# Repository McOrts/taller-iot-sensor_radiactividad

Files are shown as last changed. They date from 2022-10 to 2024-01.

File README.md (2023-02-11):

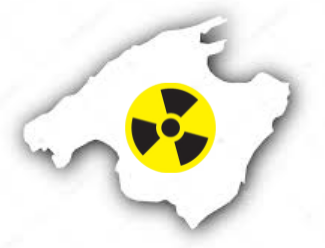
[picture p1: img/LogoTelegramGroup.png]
#  Taller sensor IoT de radiactividad
Taller IoT para construir un medidor Geiger conectado. Basado en el ESP8266, MQTT, Node-RED e integrado en la red GMC

La solución tecnológica utilizada para la plataforma de despliegue de servicios y datos. Está basada en hardware y software libre. 

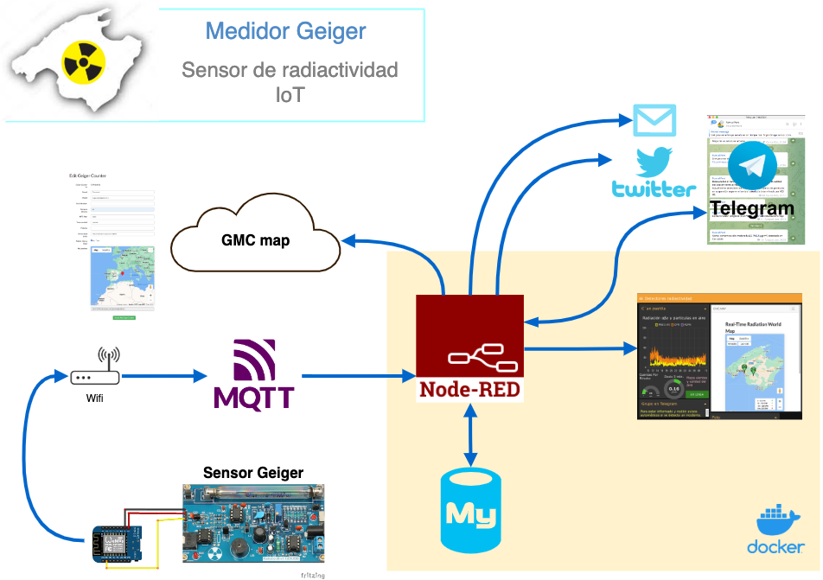
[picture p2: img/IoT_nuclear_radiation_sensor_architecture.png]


## Componentes que vamos a utilizar
**Hardware**
- [ ] 1 x [WEMOS D1 Mini Pro 16 MBytes con antena externa](https://www.aliexpress.com/item/32801063577.html)
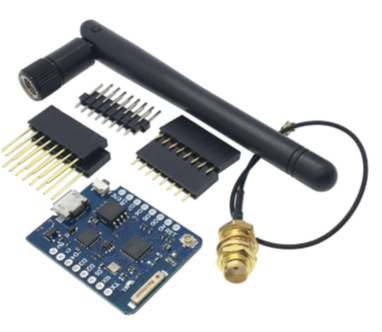
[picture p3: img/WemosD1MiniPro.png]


La placa de prototipo Wemos D1 Mini es microcontrolador muy versátil y de tamaño reducido.
  - Permite ser programado directamente desde el IDE de Arduino.
  - Ofrece pines de voltajes de salida de 3,2V y 5V.
<br>
  - Tiene conectividad Wi-Fi con todo el _stack_ de TCP/IP.
<br>
  - Incluye el chip CP2104 USB-TO-UART IC
<br>
  - El microcontrolador incorporado es el ESP-8266EX
<br>
    _  * Con un voltaje de funcionamiento: 3,3 V (chip) 5 V (placa)
<br>
    _  * Tiene 11 pines de E/S digitales: de los cuales 2 son serie y otros 2 para I2C
<br>
    _  * Pines de entrada analógica: 1 (entrada máxima: 3,2 V)
<br>
    _  * 16M bytes(128M bit) Flash
<br>

- [ ] 1 x [Contador Geiger radiación Beta Gamma ensamblado](https://es.aliexpress.com/item/1005004074447194.html)
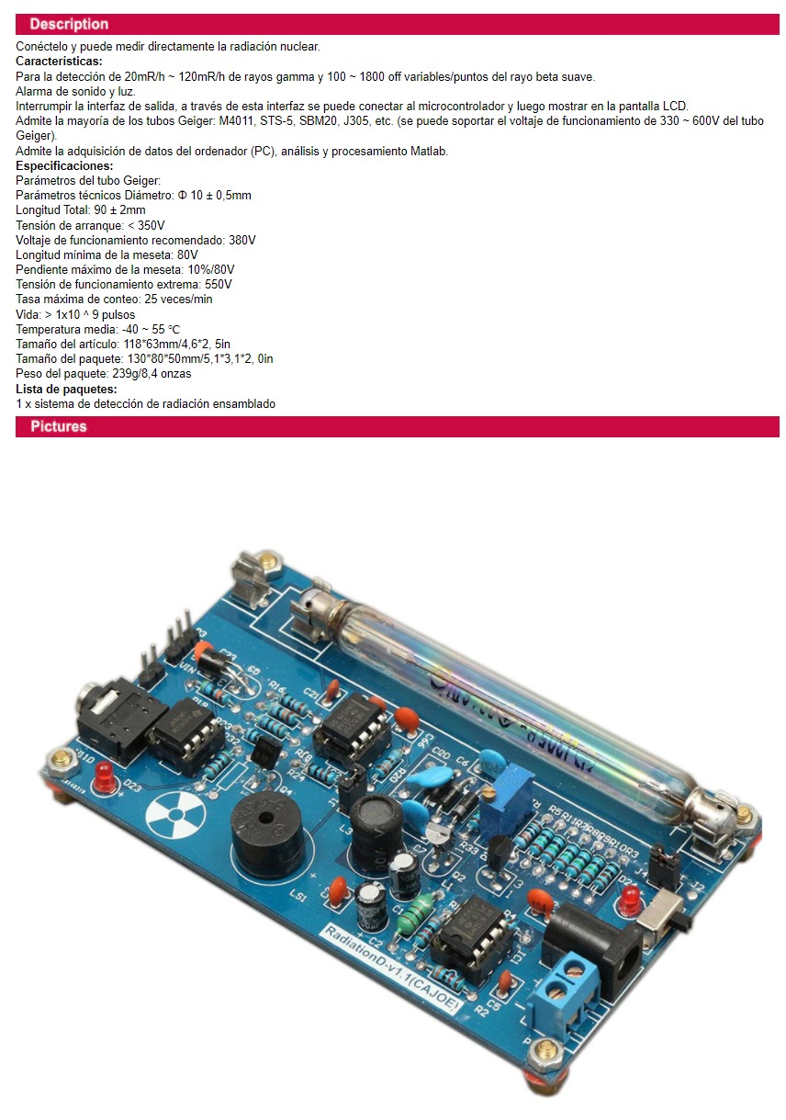
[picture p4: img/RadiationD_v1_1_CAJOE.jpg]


- [ ] 1 x [Convertidor DC-DC, 12V a 5V conector micro-USB](https://es.aliexpress.com/item/32973455778.html)
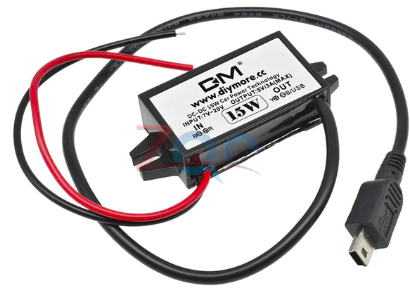
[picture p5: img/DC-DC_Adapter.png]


- [ ] 1 x [Caja impermeable para exteriores con tapa transparente de plástico ABS](https://es.aliexpress.com/item/4000852737997.html)
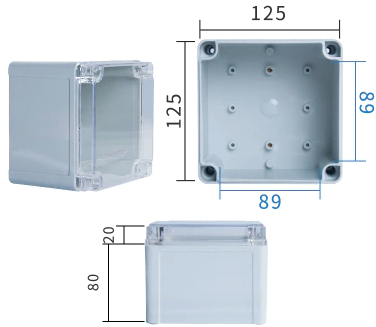
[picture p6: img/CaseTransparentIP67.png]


- [ ] 1 x [Placa protoboard para soldar](https://es.aliexpress.com/item/4001094817386.html)
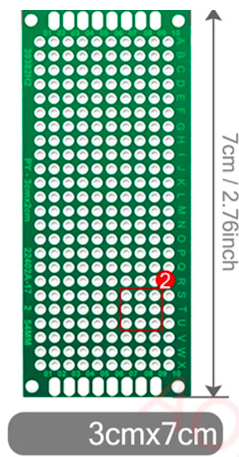
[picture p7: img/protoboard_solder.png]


- [ ] 1 x [Cable apantallado de al menos tres hilos](https://es.aliexpress.com/item/1005004134473331.html)
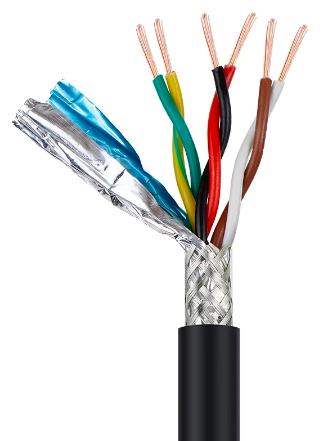
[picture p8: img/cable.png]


- [ ] 1 x [Conector para soldar en PCB](https://es.aliexpress.com/item/33025312329.html)
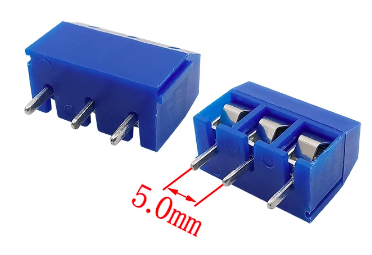
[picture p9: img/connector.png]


- [ ] 1 x [Resistencia ajustable de 10 Kohm](https://es.aliexpress.com/item/33043479672.html)
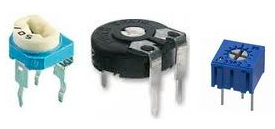
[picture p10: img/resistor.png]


- [ ] 1 x [conector dos pines IP68](https://es.aliexpress.com/item/4000058485279.html)
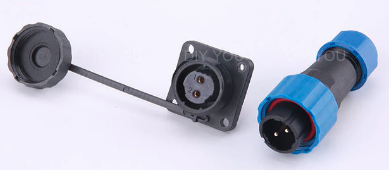
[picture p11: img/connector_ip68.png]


## Montaje
La idea es colocar y conectar todos los componentes dentro de la caja de 125x125mm de tapa transparente. Aunque el tubo Geiger irá fuera a efectos de que la caja no haga de aislamiento de la radiación alfa (α).

La conectividad es bastante sencilla aunque hay que asegurarse de una buena conexión y aislamiento ya que el dispositivo trabaja a 380V.
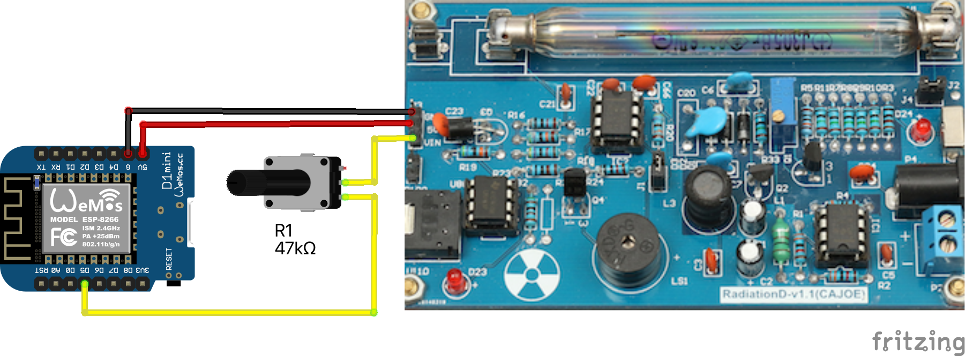
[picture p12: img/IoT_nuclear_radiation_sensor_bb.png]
Breadboard


- Lo primero será cablear la PCB según el esquema anterior.
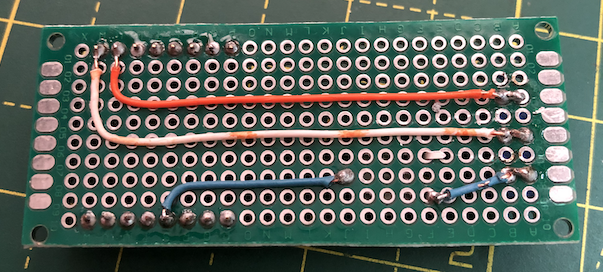
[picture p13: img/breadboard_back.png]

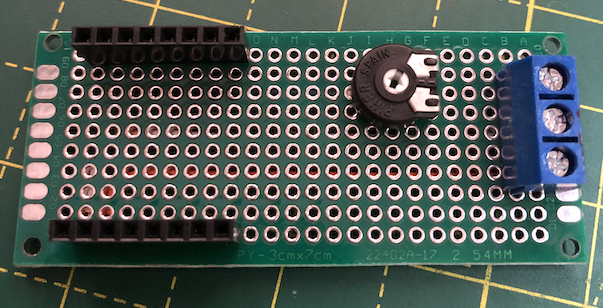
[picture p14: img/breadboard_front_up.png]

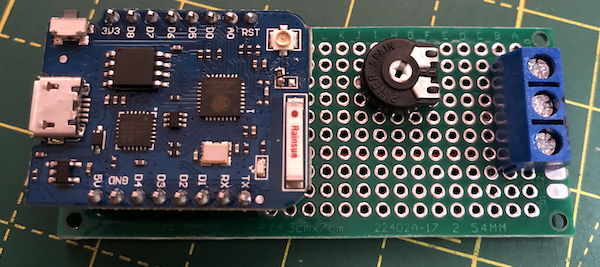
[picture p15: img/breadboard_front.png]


- Si queremos que el sensor tenga un largo alcance de conexión. Es necesario activar la salida de antena WiFi del **microcontrolador Wemos D1 mini**. Para ello hay que recolocar una resistencia de 0 ohm. Es un componente SMD por lo tanto pequeño y dificil de manejar. Hay que des-soldarlo y volver a soldar con un giro de 90º
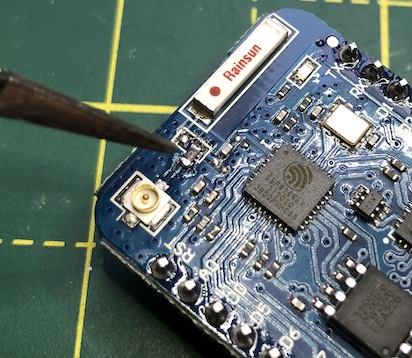
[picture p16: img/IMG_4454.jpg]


- La placa del circuito principal del sensor se fijará al fondo de la caja con dos tornillos centrales. Tras lo que tendremos a la vista el espacio para colocar el **conector de alimentación** en la parte superior derecha. Si vamos alimentar el circuito con 12V tendremos que soldar la entrada del adaptador a la parte interna de este conector.
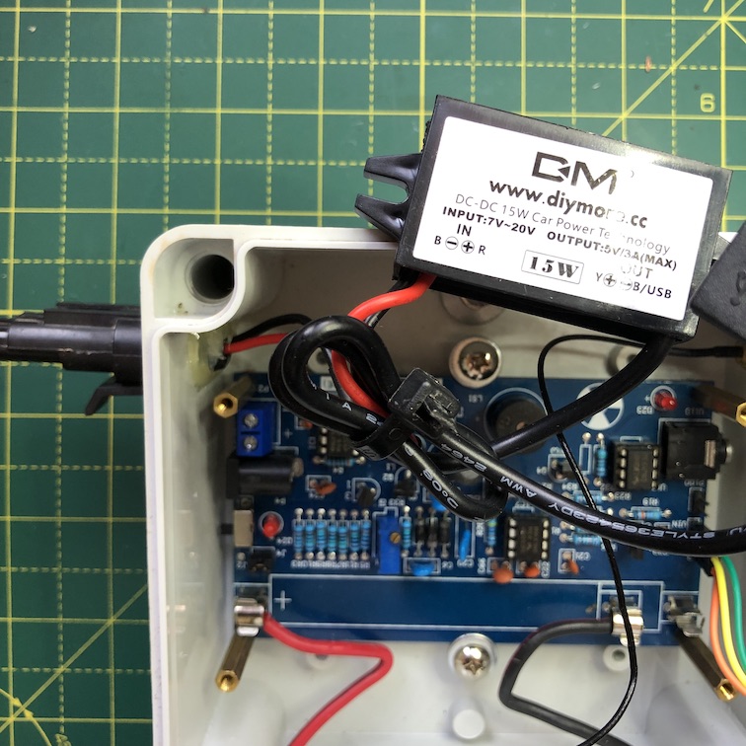
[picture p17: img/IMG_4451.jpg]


- Por otra parte vamos a preparar el **tubo Geiger** para que quede en el exterior de manera que sea más sensible a la radiación Alfa. Para ello utilizaremos dos cables gruesos, de diferentes colores para mantener la referencia de la polaridad. Estos cables van soldados directamente al tubo y a un casquillo de fusible en el otro extremo.
<br>
Nos aseguraremos de aislar bien todas las partes donde el conector del tubo haya quedado expuesto al aire. El tubo se alimenta de 380V que es una tensión peligrosa.
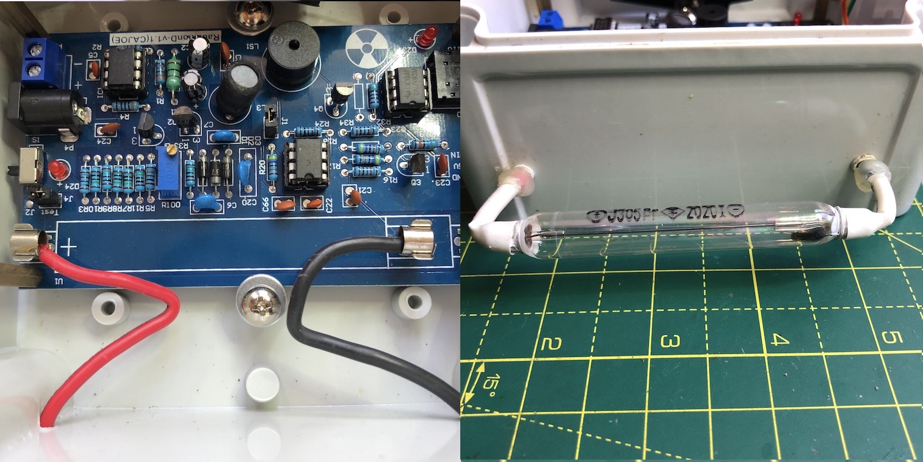
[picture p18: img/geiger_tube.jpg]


- La **antena Wifi** se podrá situar fácilmente en la esquina superior derecha de la caja:
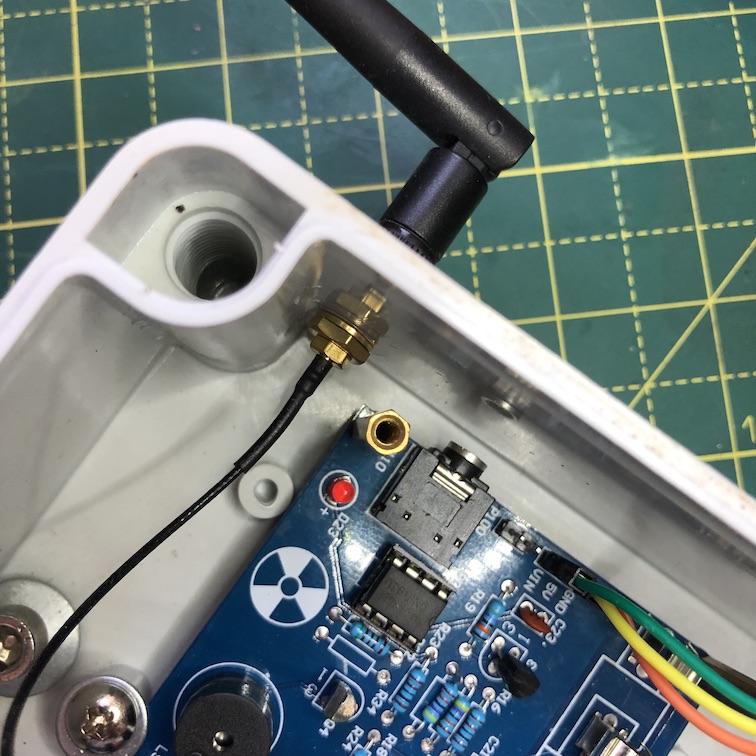
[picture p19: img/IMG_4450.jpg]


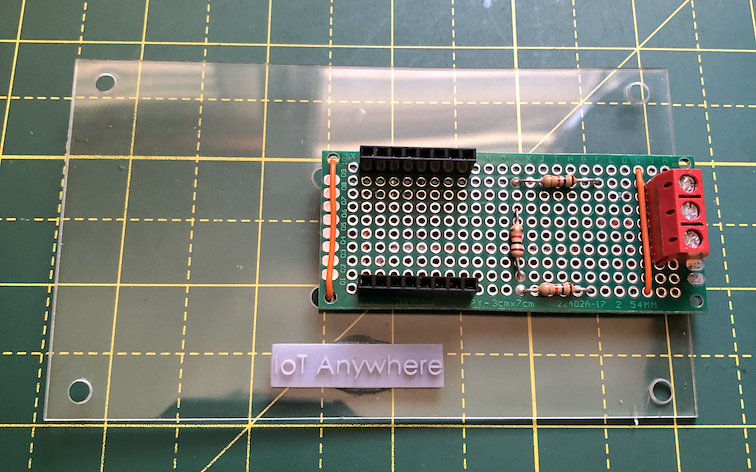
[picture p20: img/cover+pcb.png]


- Antes de fijar la placa transparente que soporta la PCB, conectaremos el cable de tres hilos.
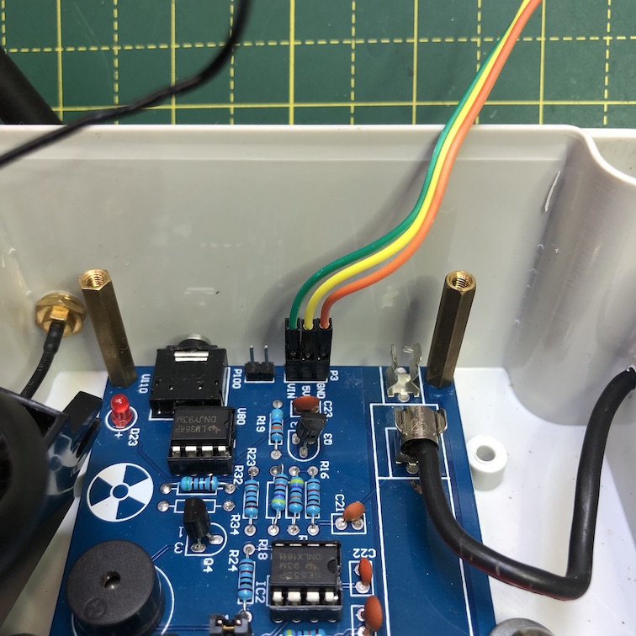
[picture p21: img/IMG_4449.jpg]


## Demo
Video de la prueba con la fuente de emisión de partículas alpha de isótopo 241 de americio.
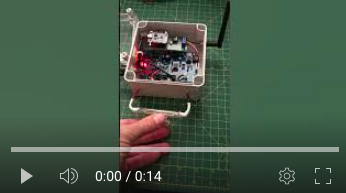
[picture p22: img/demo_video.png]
Prueba de un sensor de radiactividad conectado a internet (https://youtube.com/shorts/a5gfNajmM6I)


## Software
### 1. Instalación del IDE de Arduino (Ver 2.0.1)
Puedes descargar la última versión del IDE de Arduino desde [este sitio web](https://www.arduino.cc/en/software) si aún no la tienes.

Los sistemas Mac y Windows tienen opciones de instalación típicas. Los usuarios de Linux pueden beneficiarse de [esta información adicional](https://docs.arduino.cc/software/ide-v1/tutorials/Linux) en el sitio web de Arduino.

### 2. Añadir la placa ESP en el manager
Una vez que se haya instalado el IDE de Arduino, ábralo y haga clic en preferencias .
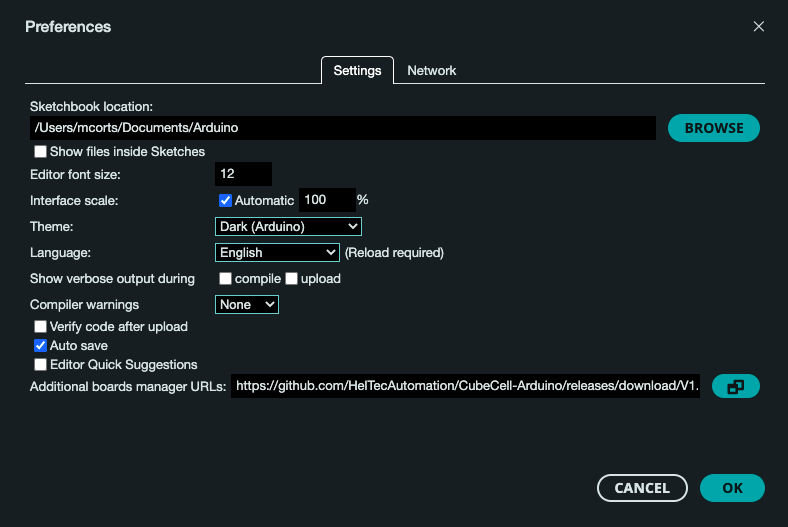
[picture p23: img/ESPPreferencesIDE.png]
 

Tendremos que agregar esta  URL em la caja de texto de "Additional board manager URLs":
```
https://arduino.esp8266.com/stable/package_esp8266com_index.json
```
Si ya hay URL registradas se puede hacer clic en el ícono pequeño a la derecha del cuadro de texto para registrar varias URL's.

### 3. Añadir las placas ESP para el configurador
Ahora podemos agregar los tableros ESP haciendo clic en la opción herramientas > tablero > administrador de tableros… en el menú.
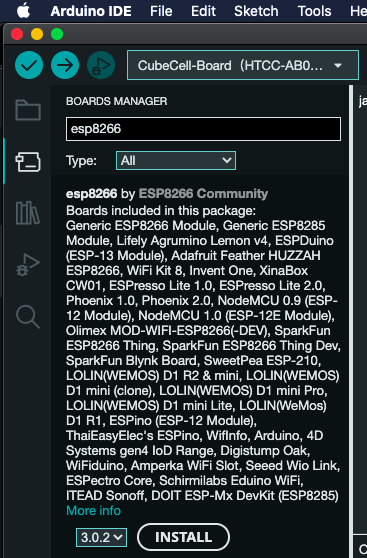
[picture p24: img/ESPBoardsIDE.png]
 

Busca el paquete ESP8266 e instálalo. Una vez que se haya instalado, puedes cerrar el administrador de placas.

### 4. Elige la placa y el puerto
A continuación, debemos seleccionar la placa Wemos D1 Mini PRO del menú de herramientas. Tendremos que seleccionar **LOLIN (WEMOS) D1 mini PRO** de los dispositivos ESP recién agregados.
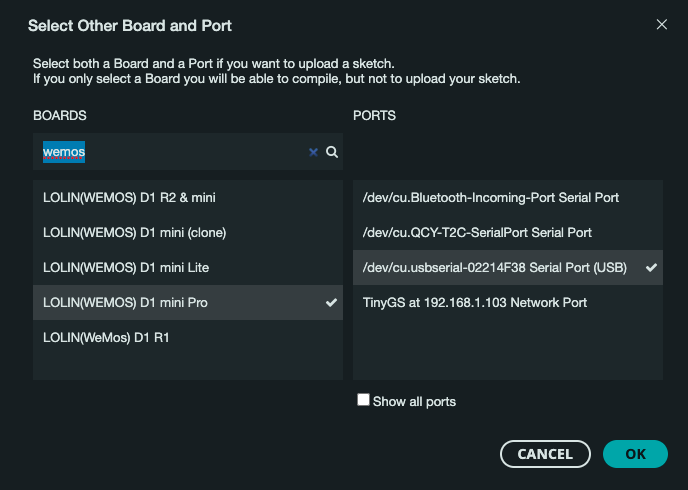
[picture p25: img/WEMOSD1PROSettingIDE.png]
 

Puede suceder que la aplicación encuentre dependencias u otras librerías des-actializadas. Aparecería un mensaje como este que deberás aceptar.
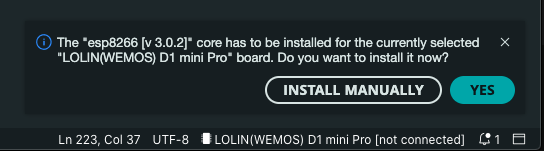
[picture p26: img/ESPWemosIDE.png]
 

Finalmente, debemos elegir el puerto correcto en el menú de herramientas . En Mac/Linux esto aparecerá como algo así como **dev/cu.usbserial-xxxx** y en Windows será **COMX\**.
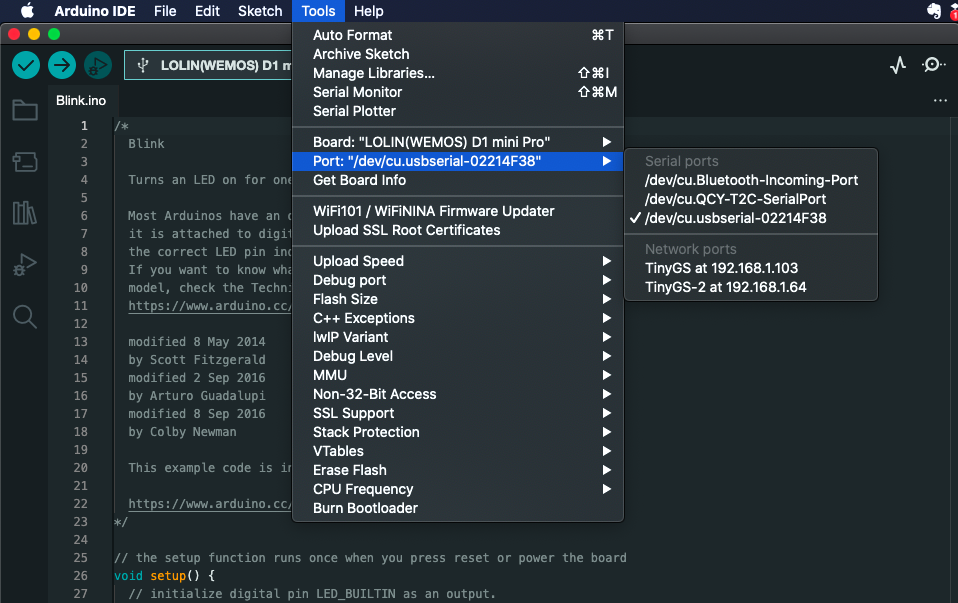
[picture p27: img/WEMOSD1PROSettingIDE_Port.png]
 

### 5. _Testing Point_
En este punto vamos a chequear todo cargando un _sketch_ que hará que la luz azul de la placa parpadee.
Este programa lo podrás encontrar en la ruta de ejemplos:

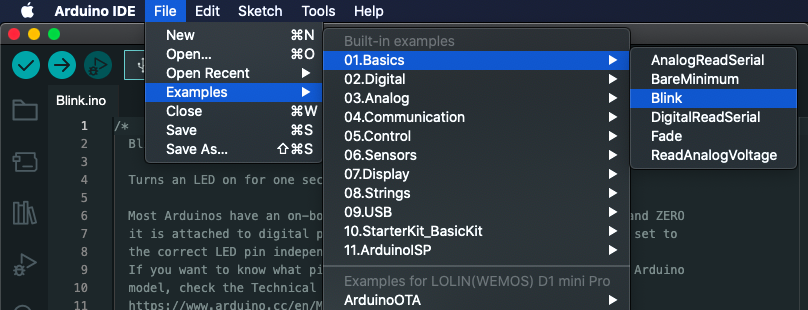
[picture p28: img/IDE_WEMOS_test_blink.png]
 

Estos serían los mensajes de salida cuando se carge el ejemplo en el microcontrolador:

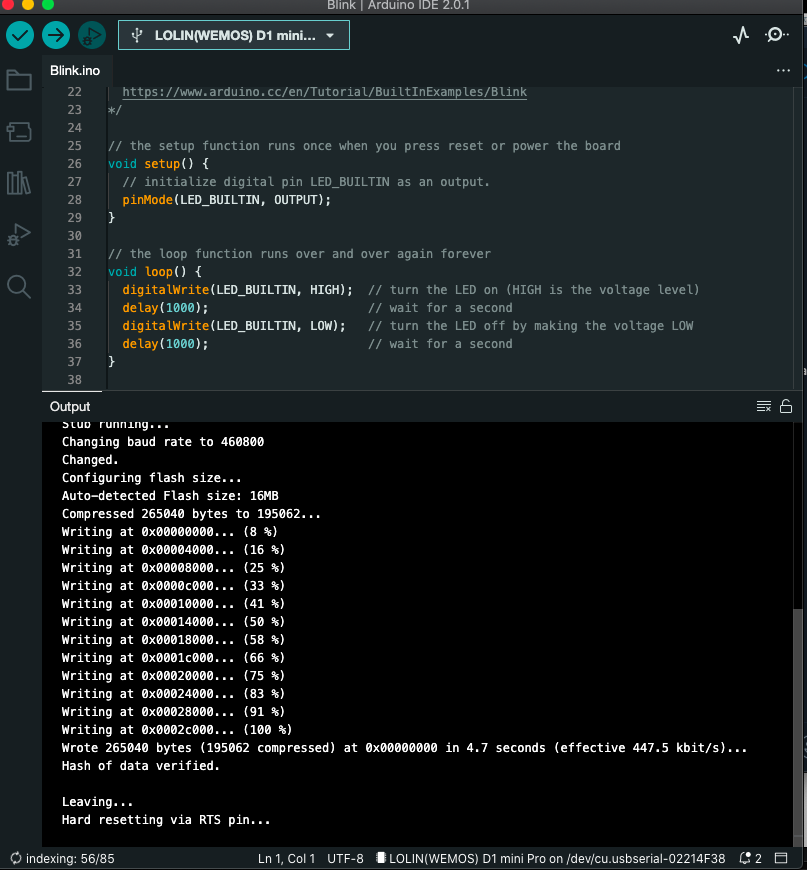
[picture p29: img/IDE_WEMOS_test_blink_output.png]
 

### 6. Añadir la librería de MQTT
Nuestro sensor va a utilizar colas MQTT para publicar sus lecturas y recbir comandos. Esta es la razón por la que hay la llamada a esta librería: 
#include <PubSubClient.h>

Por lo tanto hay se buscarla e instalarla con todas sus dependencias:
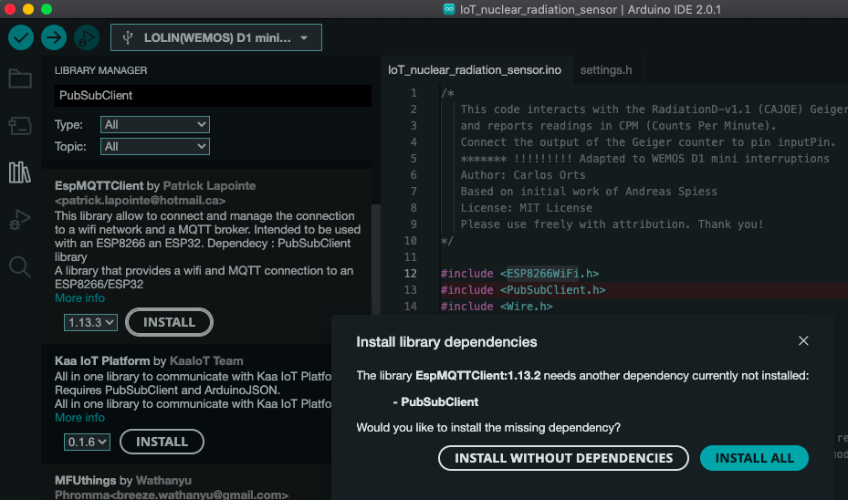
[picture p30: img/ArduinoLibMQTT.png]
 

### 7. Configuración y carga del firmware 

Con todo lo anterior configurado ahora solo tendrás que bajarte el programa de la carpeta [IoT_nuclear_radiation_sensor](./src/IoT_nuclear_radiation_sensor) que contiene el sketch de Arduino formado por dos archivos.

Uno de los archivos es el de configuración _settings.h_ que contiene las credenciales para la conexión WiFi que hay que poner, y la configuración MQTT de nuestro servidor o de uno externo.
Para hacer las pruebas iniciales hemos utilizado un servidor MQTT (Broker) público. El [HiveMQ](https://www.hivemq.com/public-mqtt-broker/) nos permite usar de una forma simple, sin usuario, este servicio.

```cpp
// WiFi Configuration
const char* ssid = "??";
const char* password = "??";

// MQTT Configuration
const char* mqtt_server = "broker.hivemq.com";
const int mqtt_port = 1883;
const char* mqtt_id = "radiation_sensor";
const char* mqtt_sub_topic_healthcheck = "/home/meteo/radiation_sensor";
const char* mqtt_sub_topic_ip = "/home/meteo/radiation_sensor/ip";
const char* mqtt_sub_topic_operation = "/home/meteo/radiation_sensor/operation";
const char* mqtt_pub_topic_radiation = "/home/meteo/radiation_sensor/cpm";

// Other params
const int pin_detector = 14; //D5
```

Con todo lo anterior configurado ahora solo tendrás que abrir [el programa](./src/IoT_nuclear_radiation_sensor/IoT_nuclear_radiation_sensor.ino) y 
Tras pulsar al botón de cargar (_upload_) y al cabo de un rato, el _firmaware_ nuevo se cargará en la placa empezando a parpadear el LED y con estos mensajes de salida en la aplicación:
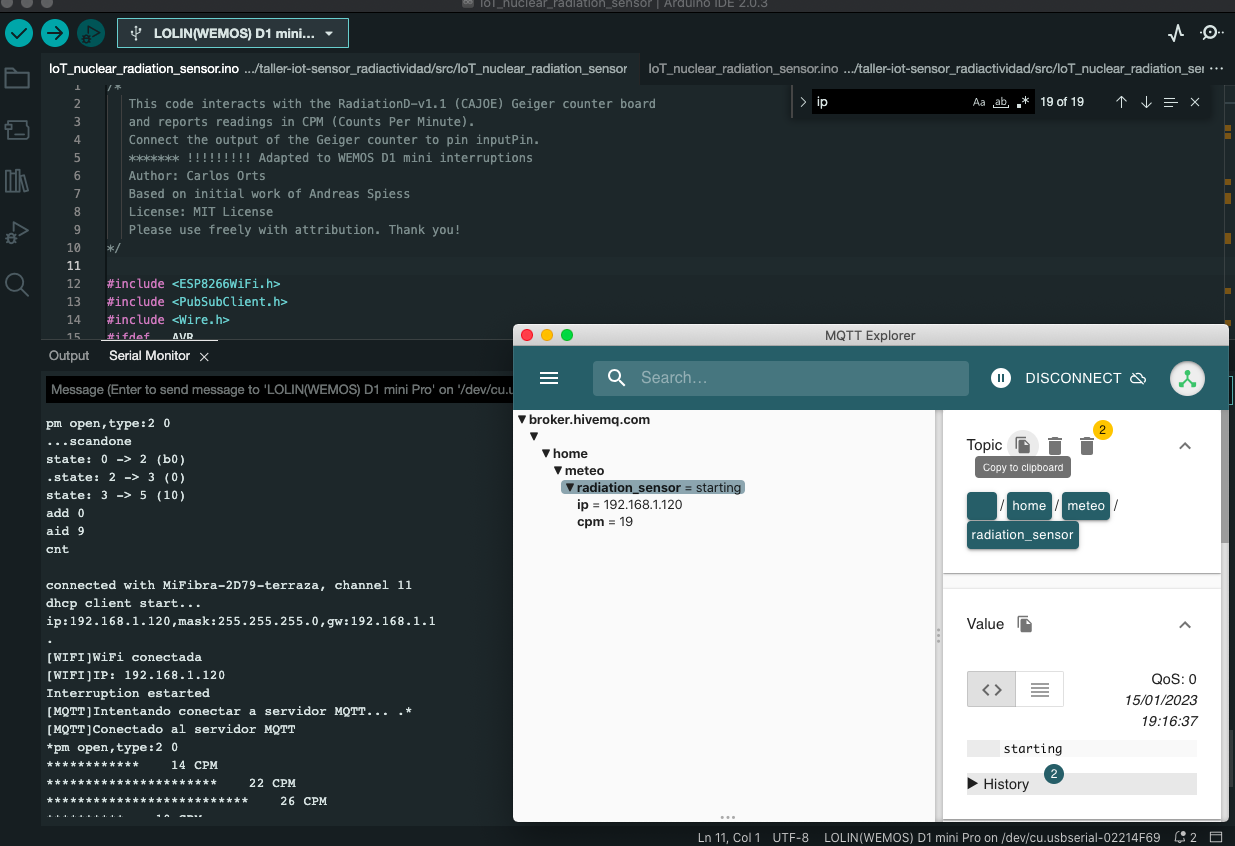
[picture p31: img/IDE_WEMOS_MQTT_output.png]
 

### Ajuste de la lectura
Puede pasar que no se estén recibiendo los datos del circuito del contador Geiger. Segurante se deba a que la resistencia variable está en un valor muy alto.

Toca ahora hacer su ajuste. Giraremos a la posición de 0 ohm hasta ver como empiezan a mostrarse las lecturas en la consola del IDE de Arduino:
```
****************    17 CPM
**************    14 CPM
*****************    17 CPM
```
Seguidamente iremos girando el ajuste hasta que dejemos de recibir la lecturas. En ese punto sólo habrá que retroceder un poco hasta que de nuevo tengamos lecturas. De esta manera ajustaremos la tensión de entrada del puerto a un valor seguro.

## Registrar el dispositivo
Vamos a utilizar la plataforma de GMC.MAP que está desarrollada por el fabricante GQ Electronics LLC y que amablemente ha abierto a la comunidad para que podamos integrar nuestros sensores en su GIS.

### Crear una cuenta
El registro del dispositivo se hace desde la web https://www.gmcmap.com/userAccountLogin-x.asp donde tendremos que darnos de alta con una dirección de correo. 

### Añade el dispositivo
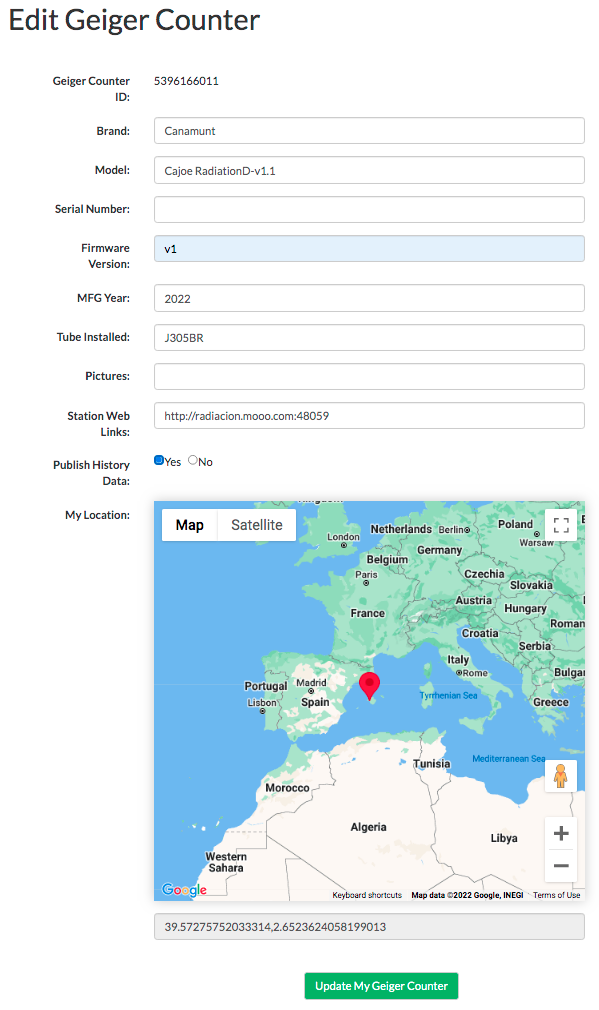
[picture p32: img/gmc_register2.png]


Desde _My account_ entramos en la opción de: _Manage my Geiger Counters_ y pulsamos: _Add a device_. Lo primero que nos pedirán será la ubicación geográfica del sensor que se determina buscando en el mapa el punto de instalación y marcando con el ratón el lugar.
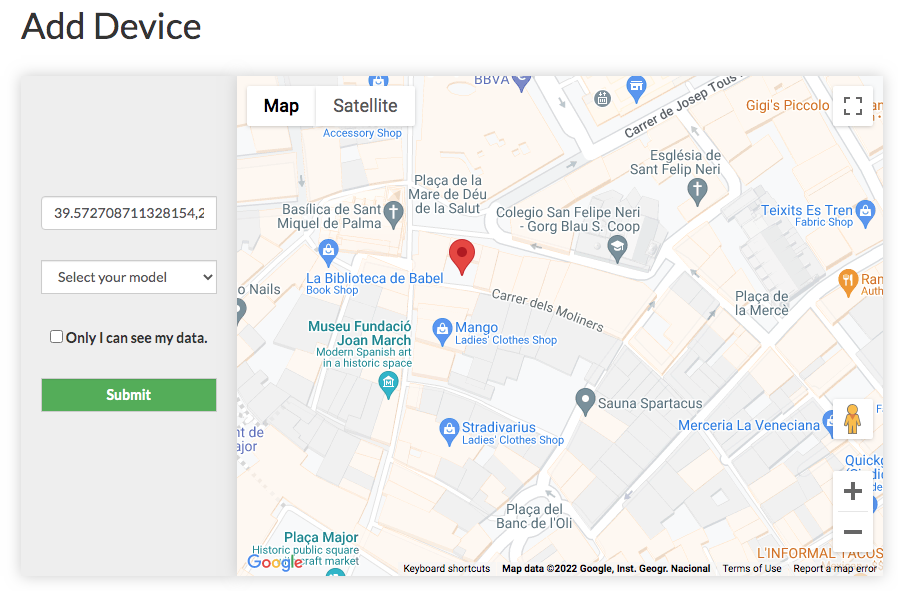
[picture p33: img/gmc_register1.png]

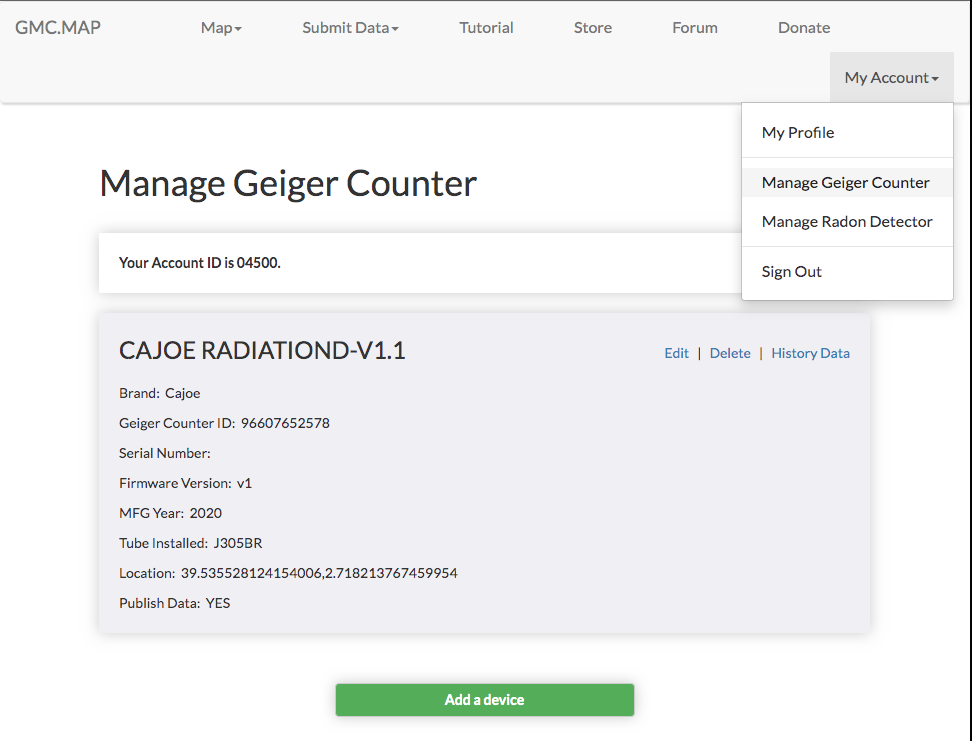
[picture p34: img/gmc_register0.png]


Hecho esto, tendremos que editar de nuevo la ficha del dispositivo para completar algunos datos más. Pulsando _Update My Geiger Counter_ habremos acabado el proceso quedándonos con el _Geiger Counter ID_ que utilizaremos para la API.
<br>
<br>
<br>
<br>
<br>

## Integración con Node-RED
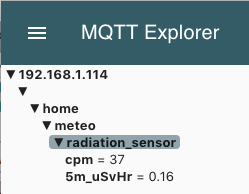
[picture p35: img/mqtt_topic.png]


Como hemos visto en la configuración del firmware del microcontrolador tenemos un servidor MQTT al que el dispositivo enviará una trama de datos cada minuto. Si visualizamos directamente el topic donde llegan estos valores, veremos esto:
- Dirección IP de red del dispositivo 
- El valor de **cpm** que es el total de pulsos por minuto. 

Para una primera prueba de recepción de datos. Tenemos este sencillo flujo cuyo código fuente lo puedes obtener en: [IoT_nuclear_radiation_sensor_Nodered_BASIC.json](./src/IoT_nuclear_radiation_sensor_Nodered_BASIC.json)

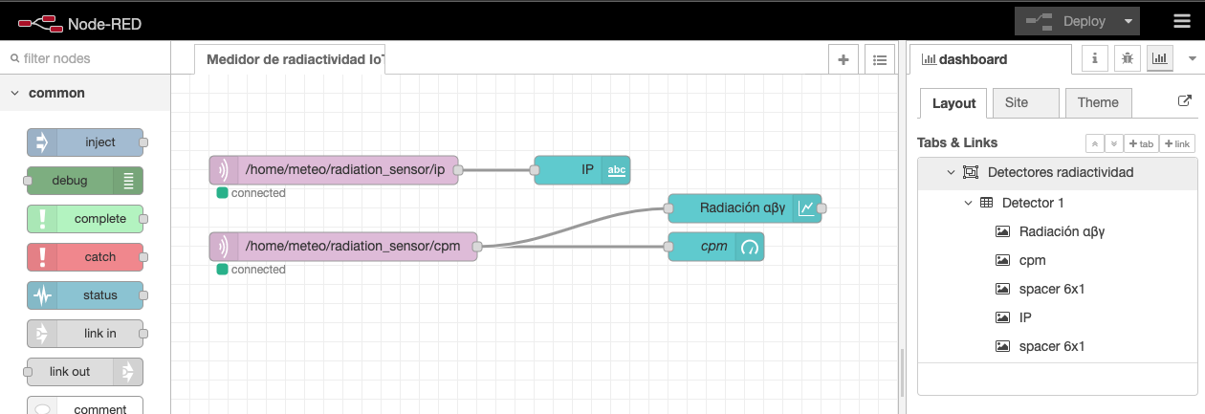
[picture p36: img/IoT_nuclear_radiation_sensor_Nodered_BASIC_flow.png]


Este programa va a subscribirse a los dos topic de MQTT para recuperar los valores de cpm e IP transmitidos por el sensor y representará sus valores en unos sencillos gráficos del dashboard de NodeRED:

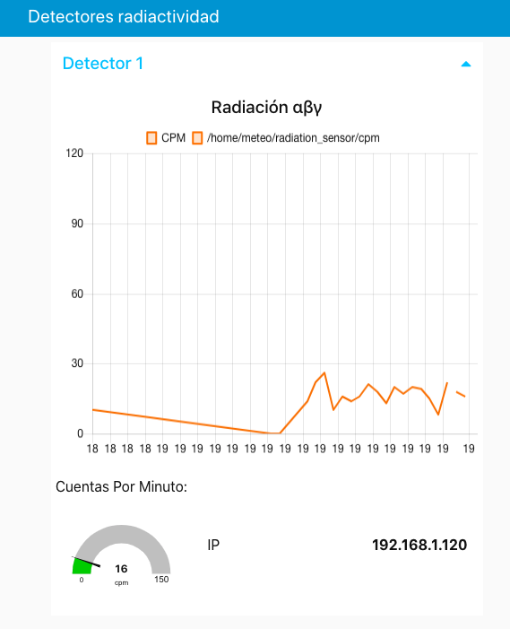
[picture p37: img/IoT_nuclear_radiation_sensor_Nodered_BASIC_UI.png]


## Integración con GMC.MAP
Vamos a utilizar la aplicación Nore-RED de control de flujos para procesar y encaminar los datos recibidos por subscripción al topic de MQTT hacia la API del servidor web de GMC.MAP. 
Este es el esquema básico del flujo cuyo código fuente lo puedes obtener en: [IoT_nuclear_radiation_sensor_Nodered_GMC.json](./src/IoT_nuclear_radiation_sensor_Nodered_GMC.json)



El primer nodo es el que lee el topic de MQTT obteniendo el mensaje JSON descrito anteriormente. El segundo, ¨Compose URL¨ crea una cadena con los parámetros y los valores para la llamada a la API. El siguiente nodo sencillamente cambia el atributo del mensaje, tiene que ser URL. Para que luego sea lanzada la petición con el método POST. El último nodo nos mostrará en la ventana de mensajes de debug la respuesta de la API. Si todo ha ido bien será: <!--sendmail.asp-->OK.ERR0 

La aplicación realmente es mas compleja porque tiene que calcular valores de media horaria y minutal. Ya que la petición API requiere de estos valores. Los campos necesarios para la petición son:
- **UserAccountID**: el identificador de usuario. Se obtiene tras el registro en la web.
- **GeigerCounterID**: el identificador único del dispositivo registrado en la web según los pasos descritos anteriormente.
- **nCPM**: número de cuentas por minuto. Es el número de partículas detectadas.
- **ACPM**: media de CPM en una hora.
- **nuSv**: micro-Sievert/hora calculados según la fórmula: ¨CMP * 0,0065¨

De esta manera nuestras lecturas serán incorporadas a esta plataforma donde nuestros datos se guardarán y el último valor será mostrado en un punto el mapa con el color en función al valor de CPM.

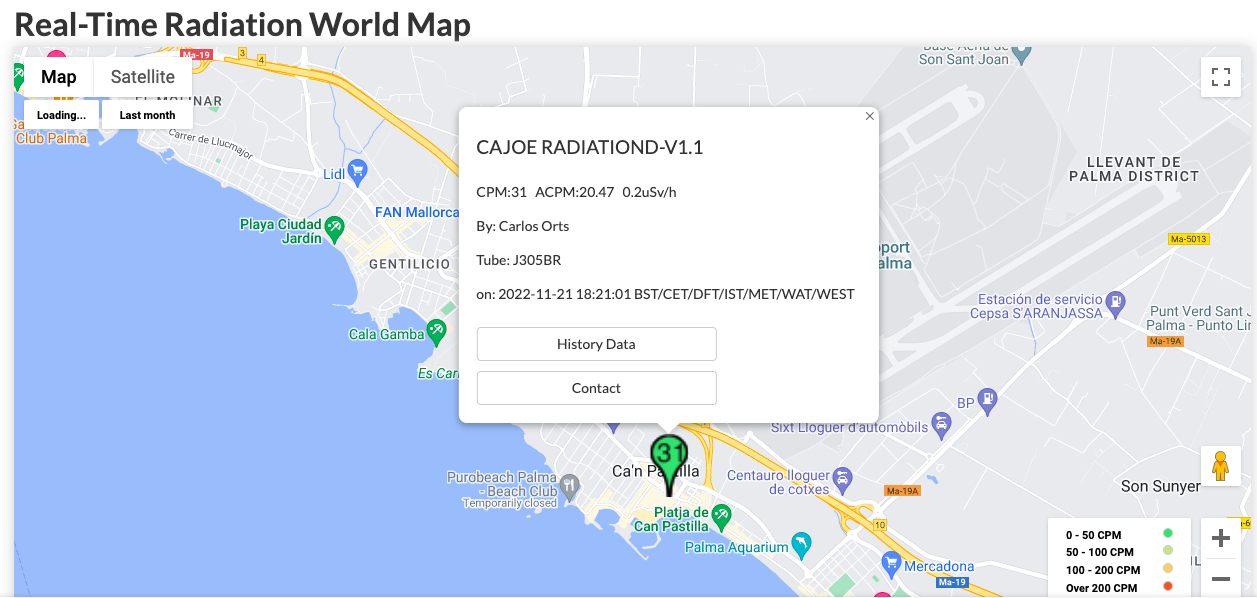
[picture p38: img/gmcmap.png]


Para este proyecto se ha ampliado la aplicación Node-RED con el fin de ofrecer una web donde observar en tiempo real las lecturas y su evolución: http://radiacion.mooo.com:48059/ui
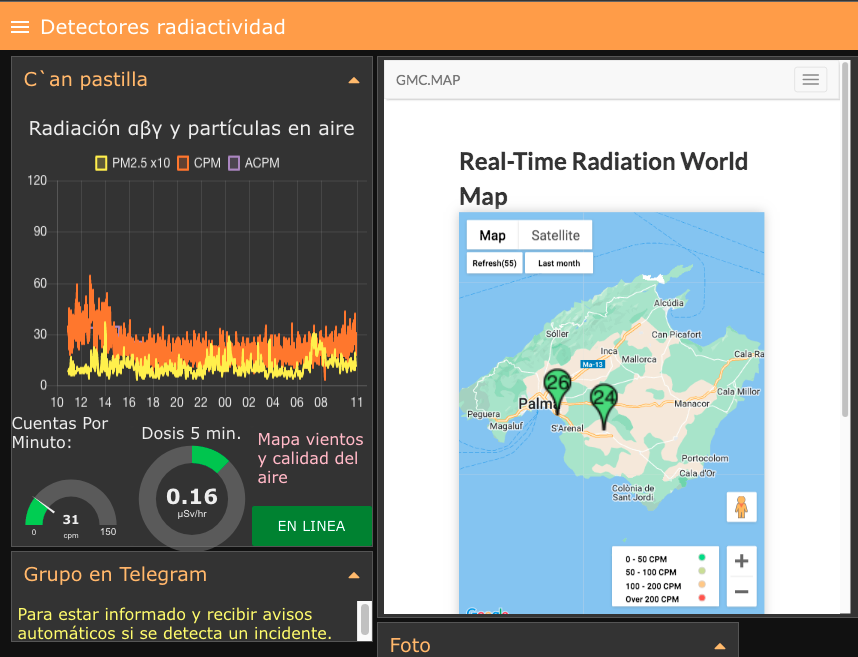
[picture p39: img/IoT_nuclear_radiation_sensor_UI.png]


El flujo necesario para esto es más complejo y su código también está repositado aquí. 
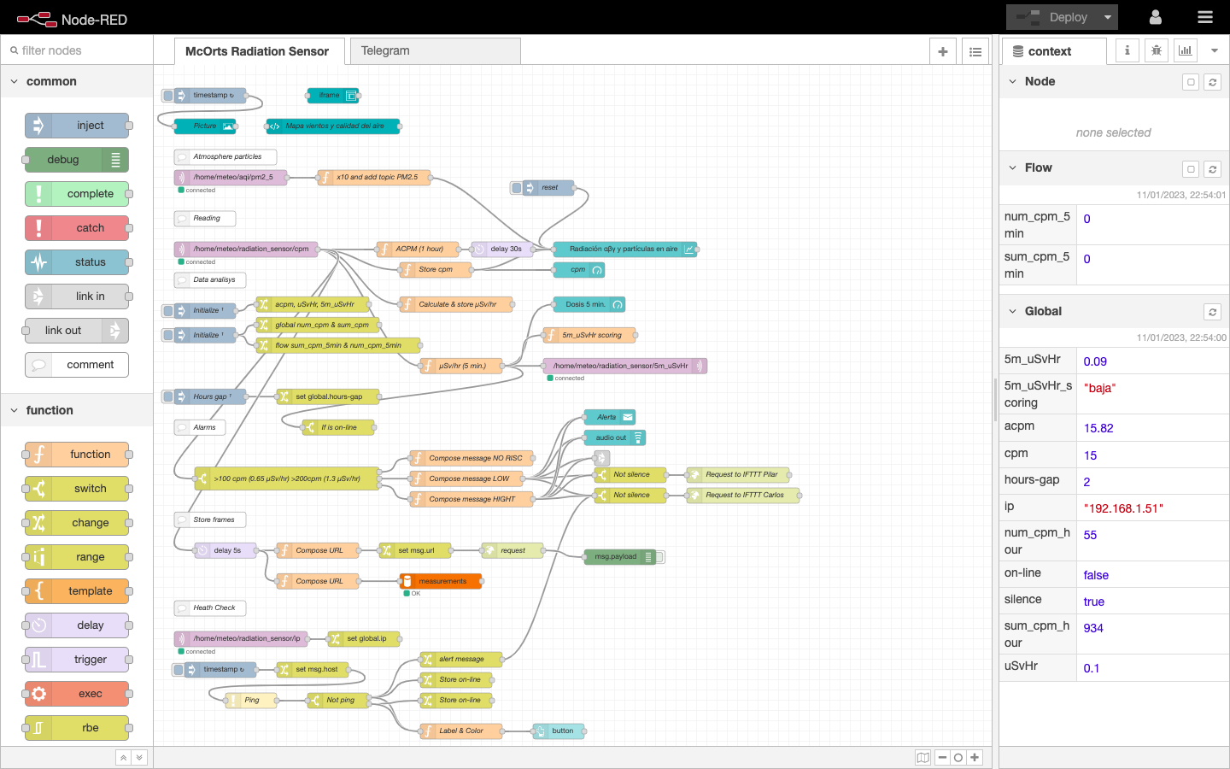
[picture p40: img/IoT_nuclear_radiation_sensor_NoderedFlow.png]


## Agradecimientos 
- Adrian Brancolino por sus buenos consejos para resolver los problemas de electrónica a los que me he enfrentado.
- [GQ Electronics LLC](https://www.gqelectronicsllc.com/) por la iniciativa de GMC.map.

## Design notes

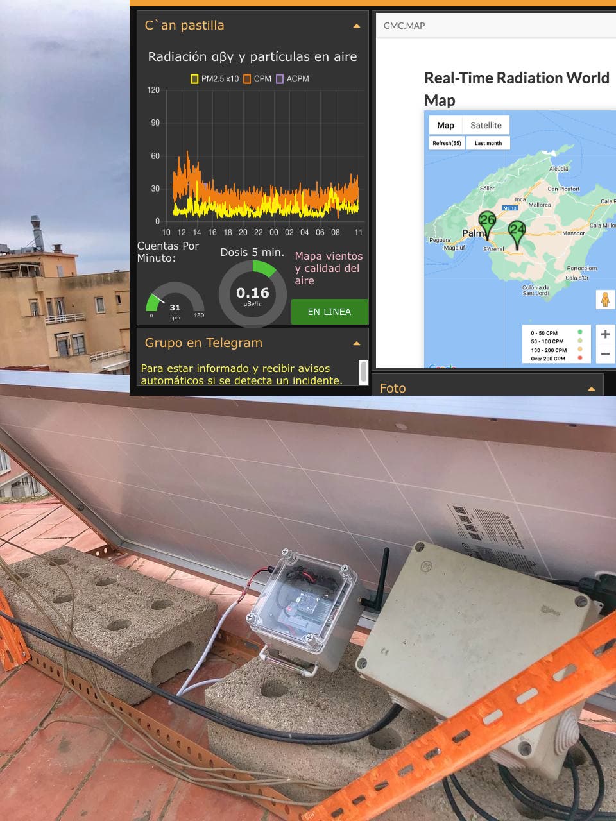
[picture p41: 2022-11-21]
img/IoTGeiger_cartel.jpg

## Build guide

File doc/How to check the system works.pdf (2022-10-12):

### How to check the system works

step1）Power on the system, use the USB cable connect the system to computer USB Port
step 2）you could hear the beep and see the led flash
how the Geiger Muller Tube works：

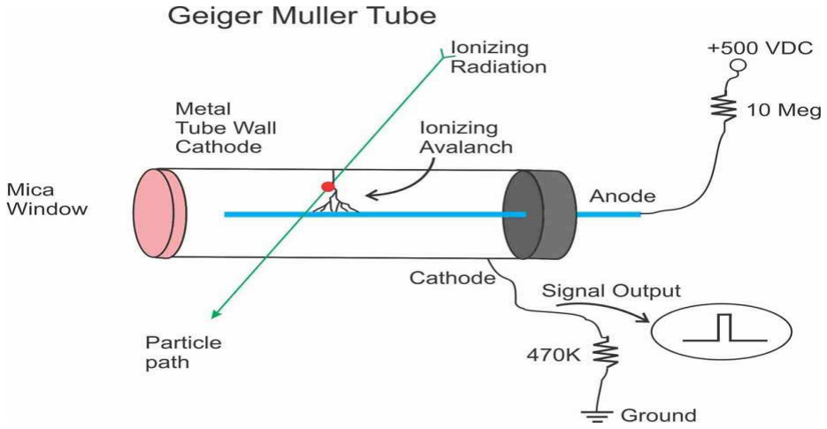
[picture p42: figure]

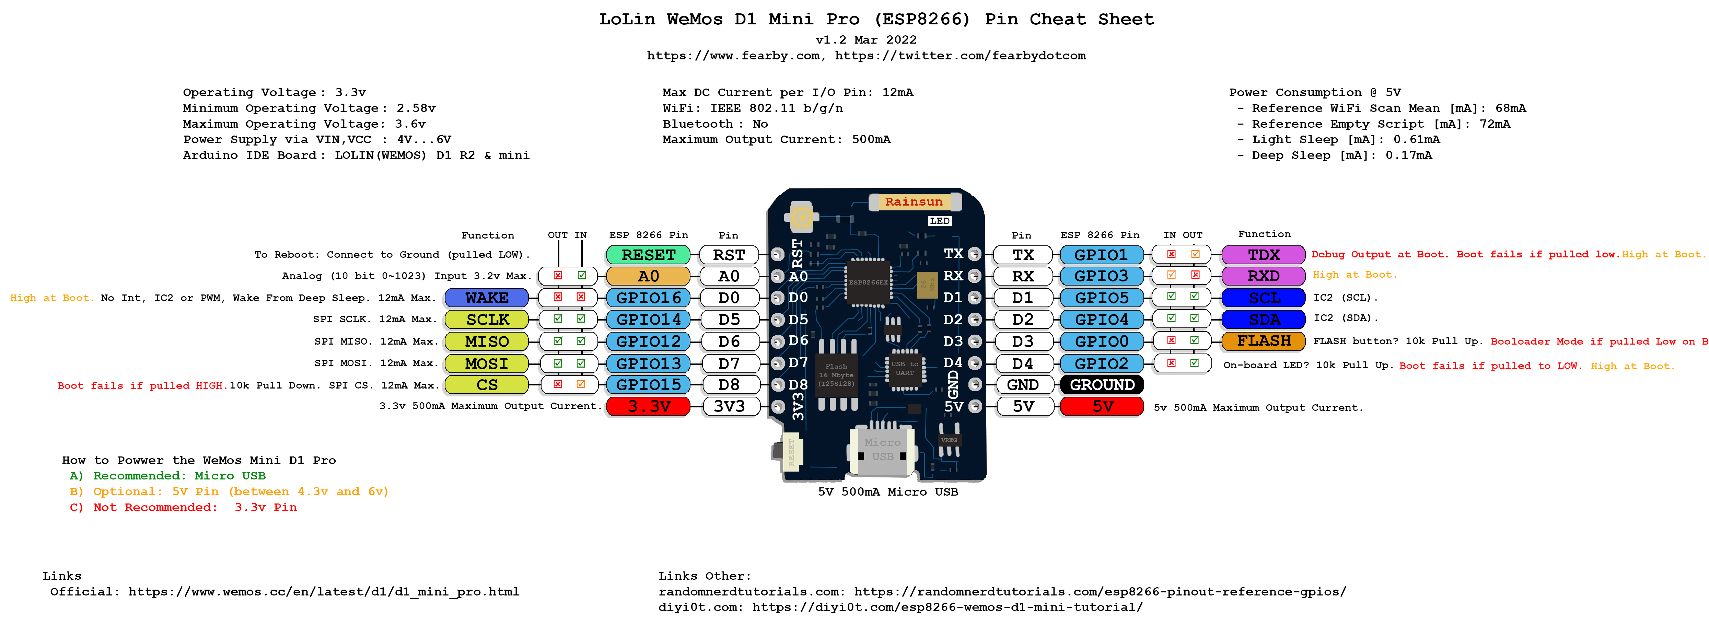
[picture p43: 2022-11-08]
img/WeMosMiniD1ProGuide.png

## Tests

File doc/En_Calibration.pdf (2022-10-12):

Calibration:
You need to calibrate the high voltage BEFORE installing Geiger tubes. The HV calibration steps are:
1. Trim P1 potentiometer to approximately 50 ohm when kit power is off.
2. Connect positive Tube Clip to pins (R6) with a jumper wrie.
3. Connect multimeter black probe to any GRN point
4. Connect multimeter probe after R10 point
5. Set your multimeter on 20V DC range.
6. Power up the device (PCB washed and IC555 installed).
7. Adjust voltage with P1 to 6.5V if you use 1M multimeter or adjust the voltage 57V if you use 10M multimeter .Use formula:Vout=Vread*((60M+Rvoltmeter)/Rvoltmeter.)

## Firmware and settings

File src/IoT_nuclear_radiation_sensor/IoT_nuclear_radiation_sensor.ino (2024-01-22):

/*
   This code interacts with the RadiationD-v1.1 (CAJOE) Geiger counter board
   and reports readings in CPM (Counts Per Minute).
   Connect the output of the Geiger counter to pin inputPin.
   ******* !!!!!!!!! Adapted to WEMOS D1 mini interruptions
   Author: Carlos Orts
   Based on initial work of Andreas Spiess
   License: MIT License
   Please use freely with attribution. Thank you!
*/

#include <ESP8266WiFi.h>
#include <PubSubClient.h>
#include <Wire.h>
#ifdef __AVR__
  #include <avr/power.h>
#endif

#include "settings.h"

/* Times for CPM calculation */
#define LOG_PERIOD 60000  //Logging period in milliseconds, recommended value 15000-60000.
#define MAX_PERIOD 60000  //Maximum logging period without modifying this sketch

unsigned long counts;     //variable for GM Tube events
unsigned long cpm;        //variable for CPM
unsigned int multiplier;  //variable for calculation CPM in this sketch
unsigned long previousMillis;  //variable for time measurement

/* Configuración cliente WiFi */
WiFiClient espClient;
String IP = String(15);

/* Configuración MQTT */
PubSubClient clientMqtt(espClient);
char msg[50];
String mqttcommand = String(14);

/* Tube pulse counter */
ICACHE_RAM_ATTR void tube_impulse() {
  counts++;
  Serial.print("*");
}

void setup() {
  Serial.begin(9600);

  /* Initialize board's LED */
  pinMode(LED_BUILTIN, OUTPUT);
  digitalWrite(LED_BUILTIN, HIGH);
  delay(500);
    
  /* Initialize wifi */
  setup_wifi();
  clientMqtt.setServer(mqtt_server, mqtt_port);
  clientMqtt.setCallback(callback);
  
  /* Times for CPM calculation */
  counts = 0;
  cpm = 0;
  multiplier = MAX_PERIOD / LOG_PERIOD;      //calculating multiplier, depend on your log period

  /* Setup GPIO sensor port */
  pinMode(pin_detector, INPUT);
  attachInterrupt(digitalPinToInterrupt(pin_detector),tube_impulse, FALLING);
  Serial.println("Interruption estarted");
  delay (1000);
}

String IpAddress2String(const IPAddress& ipAddress)
{
  return String(ipAddress[0]) + String(".") +\
  String(ipAddress[1]) + String(".") +\
  String(ipAddress[2]) + String(".") +\
  String(ipAddress[3])  ; 
}

void setup_wifi() {
  delay(10);

  // Comienza el proceso de conexión a la red WiFi
  Serial.println();
  Serial.print("[WIFI]Conectando a ");
  Serial.println(ssid);

  // Modo estación
  WiFi.mode(WIFI_STA);
  // Inicio WiFi
  WiFi.begin(ssid, password);

  while (WiFi.status() != WL_CONNECTED) {
    delay(500);
    Serial.print(".");
  }

  IP=IpAddress2String(WiFi.localIP());
  Serial.println("");
  Serial.println("[WIFI]WiFi conectada");
  Serial.print("[WIFI]IP: ");
  Serial.print(WiFi.localIP());
  Serial.println("");
}

void callback(char* topic, byte* payload, unsigned int length) {
  Serial.print("[MQTT]Mensaje recibido (");
  Serial.print(topic);
  Serial.print(") ");
  mqttcommand = "";
  for (int i = 0; i < length; i++) {
    mqttcommand += (char)payload[i];
  }
  Serial.print(mqttcommand);
  Serial.println();
  // Switch on the LED if an 1 was received as first character
  if (mqttcommand == "command") {
    Serial.println("don");
  } 
}

void reconnect() {
  Serial.print("[MQTT]Intentando conectar a servidor MQTT... ");
  // Bucle hasta conseguir conexión
  while (!clientMqtt.connected()) {
    Serial.print(".");
    // Intento de conexión
    //if (clientMqtt.connect(mqtt_id)) { // Ojo, para más de un dispositivo cambiar el nombre para evitar conflicto
    if (clientMqtt.connect(mqtt_id, mqttUser, mqttPassword )) { // Ojo, para más de un dispositivo cambiar el nombre para evitar conflicto
      Serial.println("");
      Serial.println("[MQTT]Conectado al servidor MQTT");
      // Once connected, publish an announcement...
      clientMqtt.publish(mqtt_sub_topic_healthcheck, "starting");
      clientMqtt.publish(mqtt_sub_topic_ip, IP.c_str());
      // ... and subscribe
      clientMqtt.subscribe(mqtt_sub_topic_operation);
    } else {
      Serial.print("[MQTT]Error, rc=");
      Serial.print(clientMqtt.state());
      Serial.println("[MQTT]Intentando conexión en 5 segundos");
      delay(5000);
    }
  }
}

void loop() {
  if (!clientMqtt.connected()) {
    reconnect();
  }
  clientMqtt.loop();
    unsigned long currentMillis = millis();
  if(currentMillis - previousMillis > LOG_PERIOD){
    digitalWrite(LED_BUILTIN, LOW);       
    previousMillis = currentMillis;
    cpm = counts * multiplier;
    snprintf (msg, 10, "%6i", cpm);
    clientMqtt.publish(mqtt_pub_topic_radiation, msg);   
    Serial.print(msg);
    Serial.println(" CPM");
    counts = 0;
    digitalWrite(LED_BUILTIN, HIGH);
  }
}

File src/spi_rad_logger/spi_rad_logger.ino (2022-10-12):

/*Serial Communication for Radiation Detector Arduino Compatible DIY Kit ver 2.01 or higher
* http://radiohobbystore.com/radiation-detector-geiger-counter-diy-kit-second-edition.html
* Allow to connect the kit to computer and use the kit with Radiation Logger PC software
* http://radiohobbystore.com/radiation-logger/
* This Arduino sketch written by Alex Boguslavsky RH Electronics; mail: support@radiohobbystore.com
* CPM counting algorithm is very simple, it just collect GM Tube events during presettable log period.
* For radiation monitoring station it's recommended to use 30-60 seconds logging period. Feel free to modify
* or add functions to this sketch. This Arduino software is an example only for education purpose without any
* warranty for precision radiation measurements. You are fully responsible for your safety in high
* radiation area!!
* --------------------------------------------------------------------------------------
* WHAT IS CPM?
* CPM (or counts per minute) is events quantity from Geiger Tube you get during one minute. Usually it used to 
* calculate a radiation level. Different GM Tubes has different quantity of CPM for background. Some tubes can produce
* about 10-50 CPM for normal background, other GM Tube models produce 50-100 CPM or 0-5 CPM for same radiation level.
* Please refer your GM Tube datasheet for more information. Just for reference here, SBM-20 can generate 
* about 10-50 CPM for normal background.
* --------------------------------------------------------------------------------------
* HOW TO CONNECT GEIGER KIT?
* The kit 3 wires that should be connected to Arduino UNO board: 5V, GND and INT. PullUp resistor is included on
* kit PCB. Connect INT wire to Digital Pin#2 (INT0), 5V to 5V, GND to GND. Then connect the Arduino with
* USB cable to the computer and upload this sketch. 
*/


// #include <SPI.h>
#define LOG_PERIOD 15000  //Logging period in milliseconds, recommended value 15000-60000.
#define MAX_PERIOD 60000  //Maximum logging period without modifying this sketch


unsigned long counts;     //variable for GM Tube events
unsigned long cpm;        //variable for CPM
unsigned int multiplier;  //variable for calculation CPM in this sketch
unsigned long previousMillis;  //variable for time measurement

int pin_detector = 14; //D2

//void tube_impulse(){       //subprocedure for capturing events from Geiger Kit
//  counts++;
//}

ICACHE_RAM_ATTR void tube_impulse() {
  Serial.print(".");
  counts++;
}

void setup(){             //setup subprocedure
  counts = 0;
  cpm = 0;
  multiplier = MAX_PERIOD / LOG_PERIOD;      //calculating multiplier, depend on your log period
  Serial.begin(9600);
  pinMode(pin_detector, INPUT);
  attachInterrupt(digitalPinToInterrupt(pin_detector),tube_impulse, FALLING);
  Serial.println("estarted");
  delay (1000);
}

void loop(){                                 //main cycle
  unsigned long currentMillis = millis();
  if(currentMillis - previousMillis > LOG_PERIOD){
    previousMillis = currentMillis;
    cpm = counts * multiplier;
    Serial.print("CPM: ");
    Serial.println(cpm);
    counts = 0;
  }
  
}
